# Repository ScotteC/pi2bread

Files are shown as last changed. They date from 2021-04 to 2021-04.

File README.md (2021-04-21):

## pi2bread

Just a simple connector board to distribute a Raspberry Pis GPIO port to your breadboard.

Another one? Why? Why not unsing an existing one???
Because i don't like the existing ones.
Most of the avaliable connectors distribute the pins as exact copy of the original GPIO header, including the supply pins.
This version separates signal and supply pins, add jumpers to cut the supplys and rearranges the pinuout, based on some personal needs.

## Licence

    Copyright Fabian Schöttler 2021.

    This source describes Open Hardware and is licensed under the CERN-OHL-S v2.

    You may redistribute and modify this source and make products using it under
    the terms of the CERN-OHL-S v2 ( https://ohwr.org/cernohlsv2.txt ).

    This  source  is  distributed  WITHOUT  ANY  EXPRESS  OR  IMPLIEDWARRANTY, 
    INCLUDING OF MERCHANTABILITY, SATISFACTORYQUALITY AND FITNESS FOR A PARTICULAR PURPOSE. 
    Please see the CERN-OHL-S v2 for applicable conditions.

    Source location:  https://github.com/ScotteC/pi2bread

    As per CERN-OHL-S v2 section 4, should You produce hardware based on this source, 
    You must where practicable maintain the Source Location visible on the external 
    case of the pi2bread or other products you make using this source.

You can find the full license text in the [LICENCE](LICENCE) file.

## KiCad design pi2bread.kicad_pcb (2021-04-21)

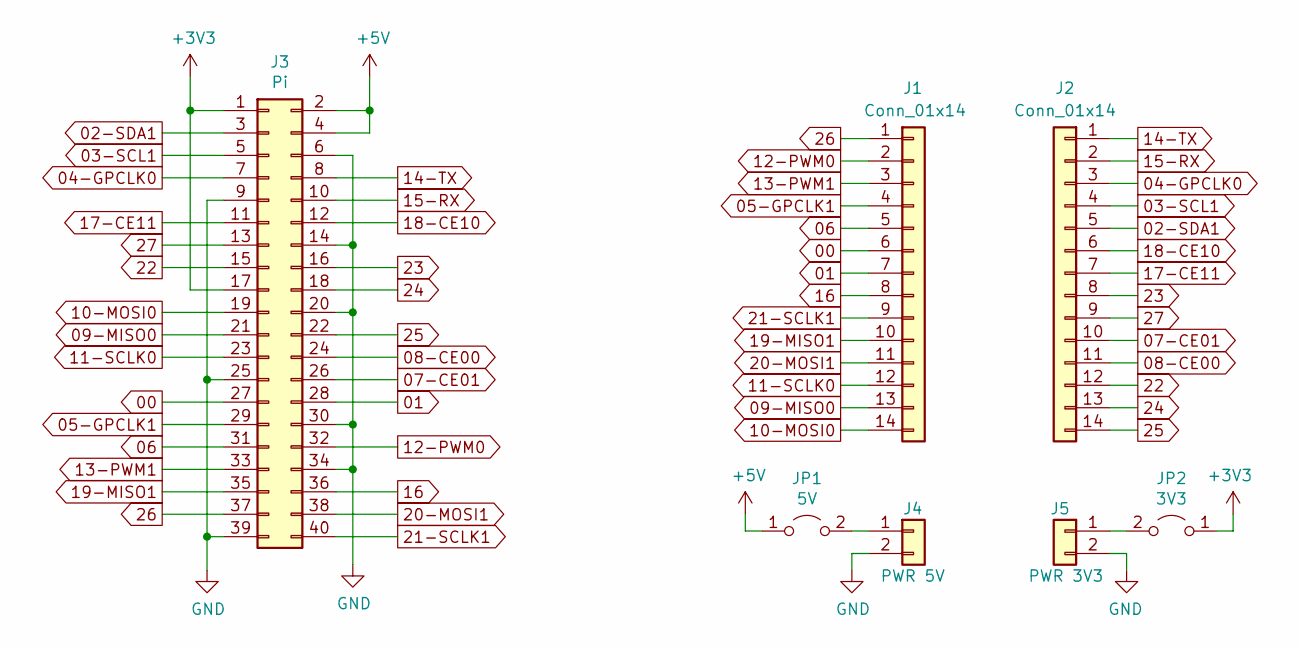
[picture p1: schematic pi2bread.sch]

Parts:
J1, J2: Conn_01x14; PinHeader_1x14_P2.54mm_Vertical
J3: Pi; vasch_strip_20x2
J4: PWR 5V; PinHeader_1x02_P2.54mm_Vertical
J5: PWR 3V3; PinHeader_1x02_P2.54mm_Vertical
JP1: 5V; PinHeader_1x02_P2.54mm_Vertical
JP2: 3V3; PinHeader_1x02_P2.54mm_Vertical

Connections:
00: J1.6, J3.27
01: J1.7, J3.28
02-SDA1: J2.5, J3.3
03-SCL1: J2.4, J3.5
04-GPCLK0: J2.3, J3.7
05-GPCLK1: J1.4, J3.29
06: J1.5, J3.31
07-CE01: J2.10, J3.26
08-CE00: J2.11, J3.24
09-MISO0: J1.13, J3.21
10-MOSI0: J1.14, J3.19
11-SCLK0: J1.12, J3.23
12-PWM0: J1.2, J3.32
13-PWM1: J1.3, J3.33
14-TX: J2.1, J3.8
15-RX: J2.2, J3.10
16: J1.8, J3.36
17-CE11: J2.7, J3.11
18-CE10: J2.6, J3.12
19-MISO1: J1.10, J3.35
20-MOSI1: J1.11, J3.38
21-SCLK1: J1.9, J3.40
22: J2.12, J3.15
23: J2.8, J3.16
24: J2.13, J3.18
25: J2.14, J3.22
26: J1.1, J3.37
27: J2.9, J3.13
+3V3: J3.1, J3.17, JP2.1 (A)
+5V: J3.2, J3.4, JP1.1 (A)
GND: J3.6, J3.9, J3.14, J3.20, J3.25, J3.30, J3.34, J3.39, J4.2, J5.2
unnamed: J4.1, JP1.2 (B)
unnamed: J5.1, JP2.2 (B)

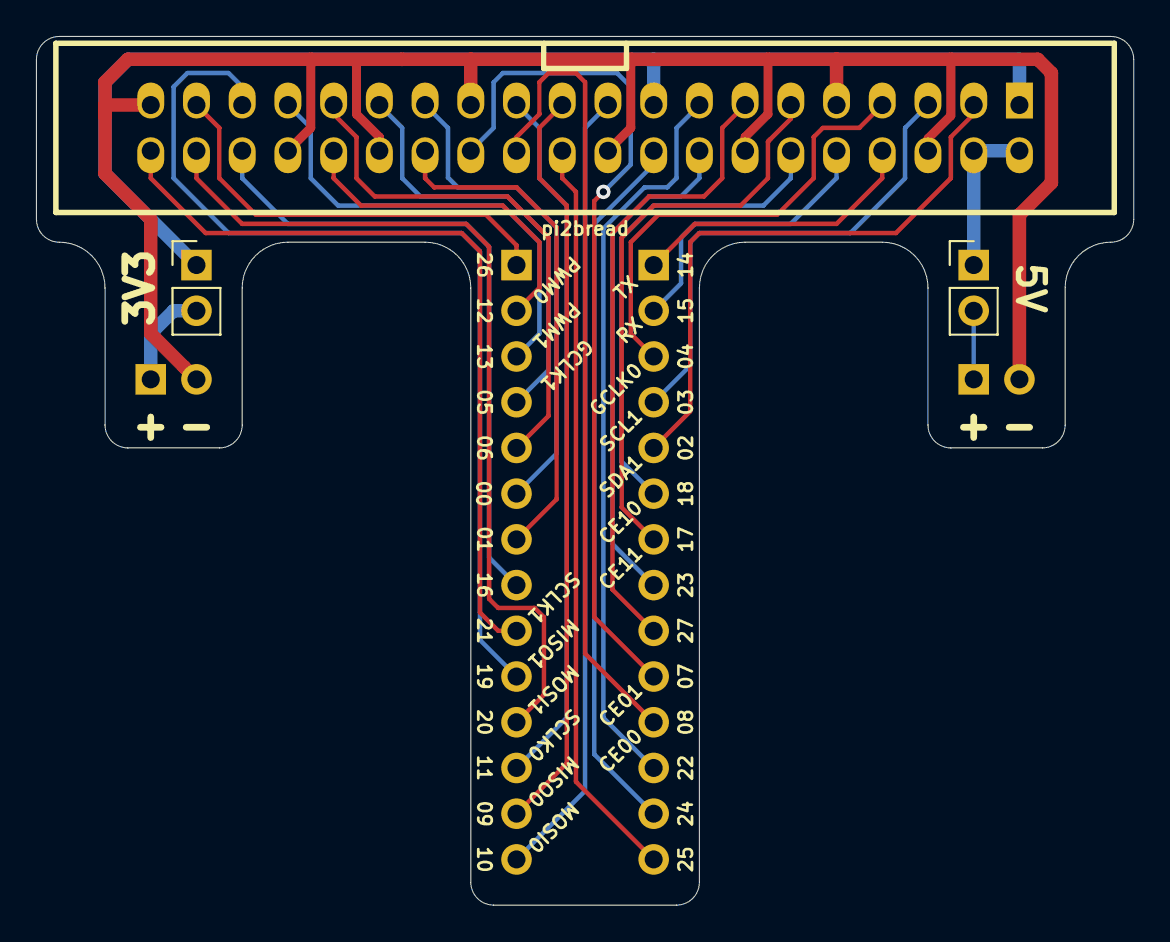
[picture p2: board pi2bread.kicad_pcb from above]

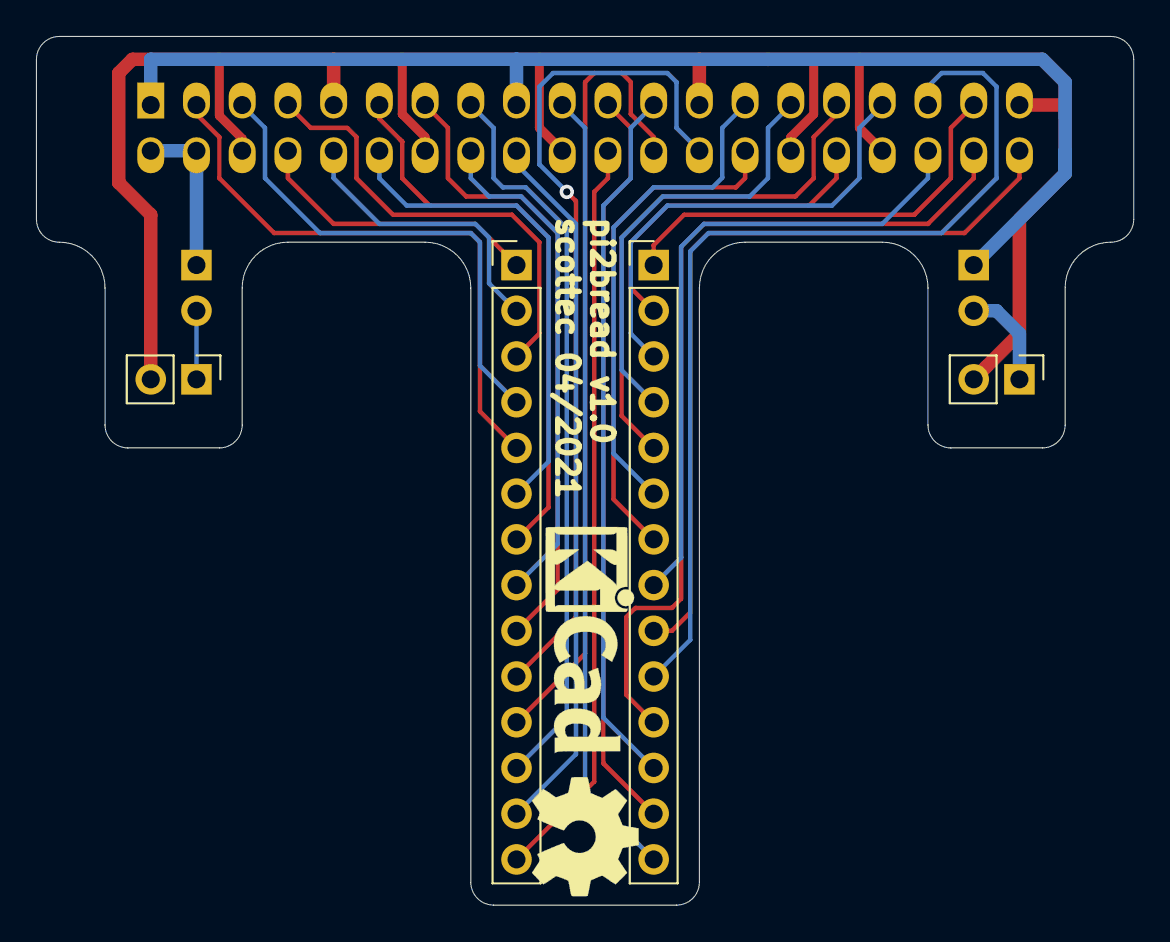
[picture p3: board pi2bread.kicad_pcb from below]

Board: 2 copper layers, 61.0 x 48.3 mm, 7 parts (4 on the bottom side), 33 nets.
